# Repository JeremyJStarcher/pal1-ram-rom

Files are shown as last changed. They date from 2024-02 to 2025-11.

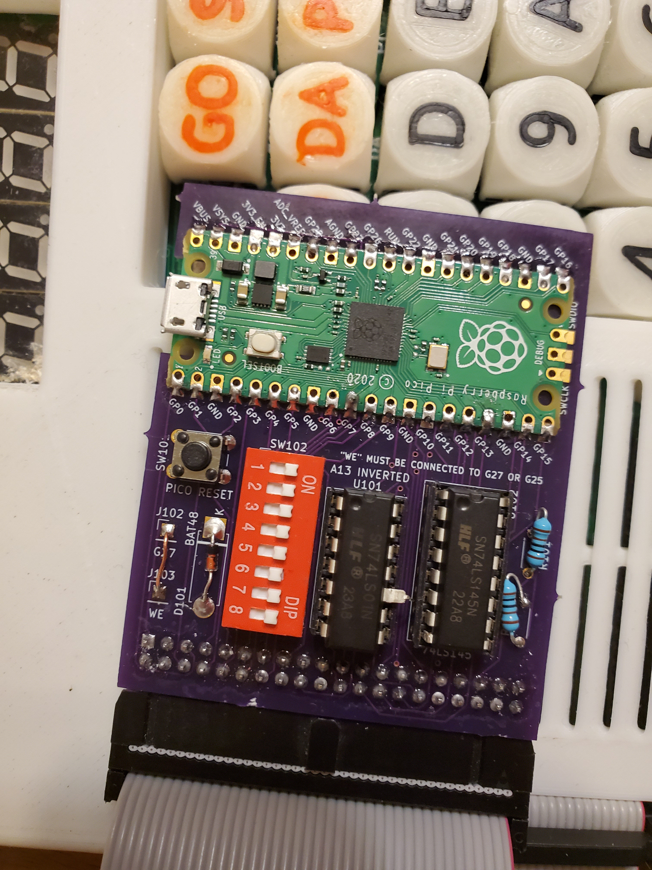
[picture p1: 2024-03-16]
pics/20240308_011445.jpg

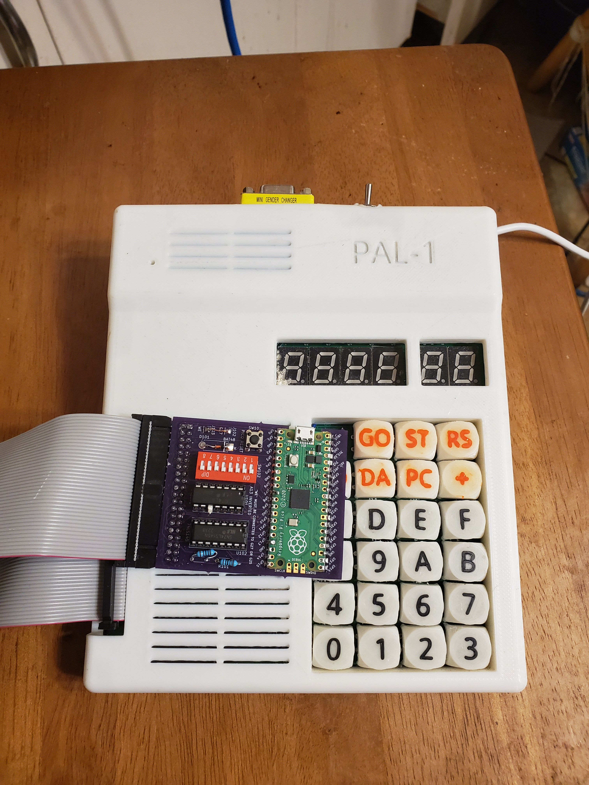
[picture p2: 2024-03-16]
pics/20240308_011429.jpg

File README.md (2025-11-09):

#Breaking change #2

# pal1-ram-rom

Configurable RAM ROM for the PAL-1 (kim-1 clone)

This project is still under development to replace the RAM/ROM and IO expansion board with a Pi Pico.

Current state:  The prototype worked after some manual board rework.

Trying to take over the DEN line via software so all ICs except the Pi Pico can be removed from the board.

## KIM-1 Memory Map

* K0 $0000 - $03FF 1024 bytes of RAM (8*6102)
* K1 $0400 - $07FF free
* K2 $0800 - $0BFF free
* K3 $0C00 - $0FFF free
* K4 $1000 - $13FF free
* K5 $1400 - $16FF free
  * $1700 - $173F I/O, timer of 6530-003
  * $1740 - $177F I/O, timer of 6530-002
  * $1780 - $17BF 64 bytes RAM of 6530-003
  * $17C0 - $17FF 64 bytes RAM of 6530-002
* K6 $1800 - $1BFF 1024 bytes ROM of 6530-003
* K7 $1C00 - $1FFF 1024 bytes ROM of 6530-002

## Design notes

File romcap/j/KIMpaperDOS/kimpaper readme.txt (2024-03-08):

    KIM-1 Mos Technology BIN - papertape format conversion utility

    Hans Otten, June 8 2007, November 2019 March 2020

    Version 1.1 (MOS Technology object format papertape, TASM compatible)

    Applicable license:

    Creative Commons Naamsvermelding-NietCommercieel 2.5 Nederland

    See http://creativecommons.org/licenses/by-nc/2.5/nl/

    Remake of PDP-11 RSX-11M KIM utilities
    Rewrite in Turbo Pascal
    Rewrite in Feepascal compilable on Windows and Linux

    PAPER TAPE FORMAT
    The paper tape is
    a specific format designed to insure error free recovery.  Each byte
    of data to be stored is converted to two half bytes.  The half bytes
    (whose possible values are 0 to F HEX) are translated into their ASCII
    equivalents and written out onto paper tape in this form.

    Each record outputted
    - begins with a ";" character (ASCII 3B) to mark the start of a valid record.
    - The next byte transmitted (max 18 HEX) or (24 10) is the number of data bytes
      contained in the record.
    - The record's starting address High (1 byte, 2 characters),
    - starting address Lo (1 byte, 2 characters),
    - and data (max 24 bytes, 48 characters) follow.

    Each record is terminated by
    - the record's check-sum (2 bytes, 4 characters),
    - a carriage return (ASCII OD),
    - line feed (ASCII 0A),
    - and six "NULL" characters (ASCII 00).

    The last record transmitted has
    - zero data bytes (indicated by 00).
    - The starting address field is replaced by a four digit Hex number
      representing the total number of data records contained in the transmission,
    - followed by the records usual check-sum digits.

    - A "XOFF" character ends the transmission.

    Example

    ;180000FFEEDDCCBBAA0099887766554433221122334455667788990AFC
     --    --  --  --  --  --  --  --  --  --  --  --  --  ----
    ;0000010001
     ----    ----

    See the mpascalint.obj file for a more complicated papertape, created with the assember TASM Commandline
    
    > tasm -65 -g1 mpascalint.asm

    deliverS mpascalint.obj with many different load addresses

    (TASM Assembler Version 3.2 2001 Squak Valley Software)

    In this implementation output of XOFF and NULL characters is suppressed
    Papertape file output is pure ASCII
    While reading a papertapefile all controll chars except LFCR are ignored
    including UTF-8 overhead. UTF-8 is therefore acceptable input.

    Also the last record is ignored after the 00 bytes (for compatibility with TASM320)

    Borland Pascal 7 syntax

    Compiled with Freepascal:
    > fpc -Mtp kimpaper.pas
     
    Long file name support, 32 bit code due to FreePascal! 

E:\BP>kimpaper
KIM-1 Mos Technology BIN - papertape format conversion utiliy, Hans Otten, 2007

Syntax is: KIMPAPER [-[b|p] filename [startaddress]

E:\BP>kimpaper -h
KIM-1 Mos Technology BIN - papertape format conversion utiliy, Hans Otten, 2007
Syntax is: KIMPAPER [-[b|p|h] filename [startaddress]
 first parameter switches
        -h help
        -p convert to papertape
        -b convert to binary

second parameter (first if no parameters, assumed binary to papertape)
               name of file to convert
               .BIN for binary, forces conversion to PAPertape
               .PAP for papertape, forces conversion to BINary

third parameter (assumed 0000 if not present)
    startaddress for BIN to papertape conversion

Files of type .BIN wil force conversion to papertape.PAP
Files of type .PAP wil force conversion to binary .BIN

If the startaddress changes in the record to a different load address nn-contigious witht he previous the current BIN file is closed and a new one,
with a sequence number is created.

For every BIN file the load address is displayed in the screen. 
See the mpascalint.obj and the many BIN files results, each displayed with a corresponding load address.

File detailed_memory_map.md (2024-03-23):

                                                                        
| ADDRESS |      AREA      | LABEL |              FUNCTION               |
|         |                |       |                                     |
|  00EF   |                | PCL   | Program Counter - Low Order Byte    |
|  00F0   |                | PGH   | Program Counter - High Order Byte   |
|  00F1   |     Machine    | P     | Status Register                     |
|  00F2   |     Register   | SF    | Stack Pointer                       |
|         |     Storage    |       |                                     |
|  00F3   |     Buffer     | A     | Accumulator                         |
|  00F4   |                | Y     | Y-Index Register                    |
|  00F5   |                | X     | X-Index Register                    |
|  1700   |                | PAD   | 6530-003 A Data Register            |
|  1701   |   Application  | PADD  | 6530-003 A Data Direction Register  |
|  1702   |        I/O     | PBD   | 6530-003 B Data Register            |
|  1703   |                | PBDD  | 6530-003 B Data Direction Register  |
|  1704   |                |       | 6530-003 Interval Timer             |
|         | Interval Timer |       |   (See Section 1.6 of               |
|         |                |       |    Hardware Manual)                 |
|  170F   |                |       |                                     |
|  17F5   |                | SAL   | Starting Address - Low Order Byte   |
|  17F6   |   Audio Tape   | SAH   | Starting Address - High Order Byte  |
|  17F7   |   Load & Dump  | EAL   | Ending Address - Low Order Byte     |
|  17F8   |                | EAH   | Ending Address - High Order Byte    |
|  17F9   |                | ID    | File Identification Number          |
|  l7FA   |                | NMIL  | NMI Vector - Low Order Byte         |
|  l7FB   |                | NMIH  | NMI Vector - High Order Byte        |
|  l7FC   |   Interrupt    | RSTL  | RST Vector - Low Order Byte         |
|         |    Vectors     |       |                                     |
|  17FD   |                | RSTH  | RST Vector - High Order Byte        |
|  l7FE   |                | IRQL  | IRQ Vector - Low Order Byte         |
|  17FF   |                | IRQH  | IRQ Vector - High Order Byte        |
|  1800   |                | DUMPT | Start Address - Audio Tape Dump     |
|         |  Audio Tape    |       |                                     |
|  1873   |                | LOADT | Start Address - Audio Tape Load     |
|  1C00   | STOP Key + SST |       | Start Address for NMI using KIM     |
|         |                |       | "Save Nachine" Routine (Load in     |
|         |                |       | 17FA & 17FB)                        |
|  17F7   |   Paper Tape   | EAL   | Ending Address - Low Order Byte     |
|  17F8   |    Dump (Q)    | EAH   | Ending Address - High Order Byte    |

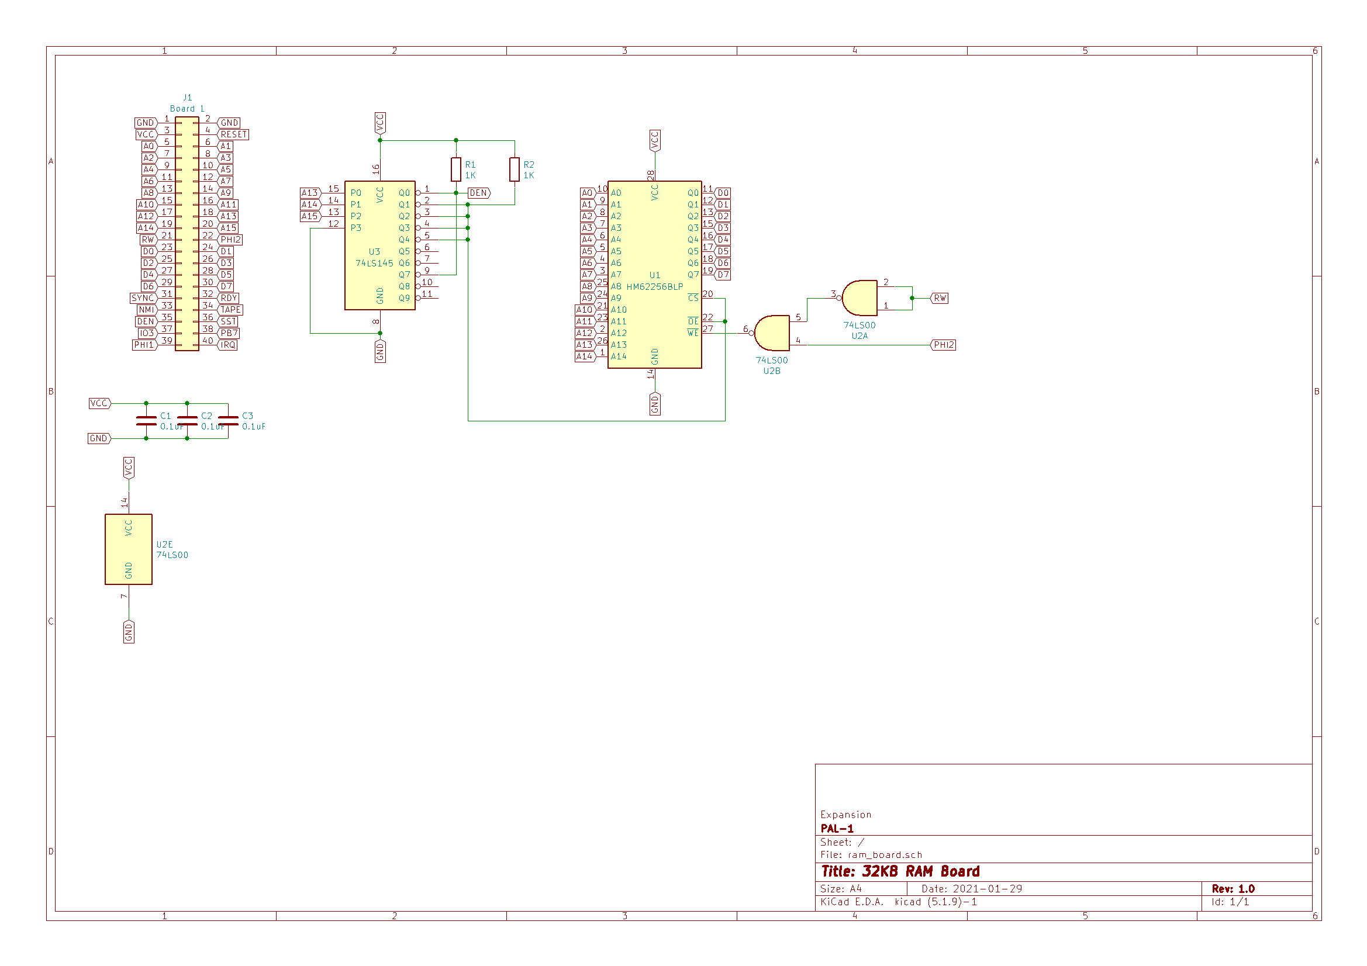
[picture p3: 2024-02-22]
32k_ram_board_schematic.png

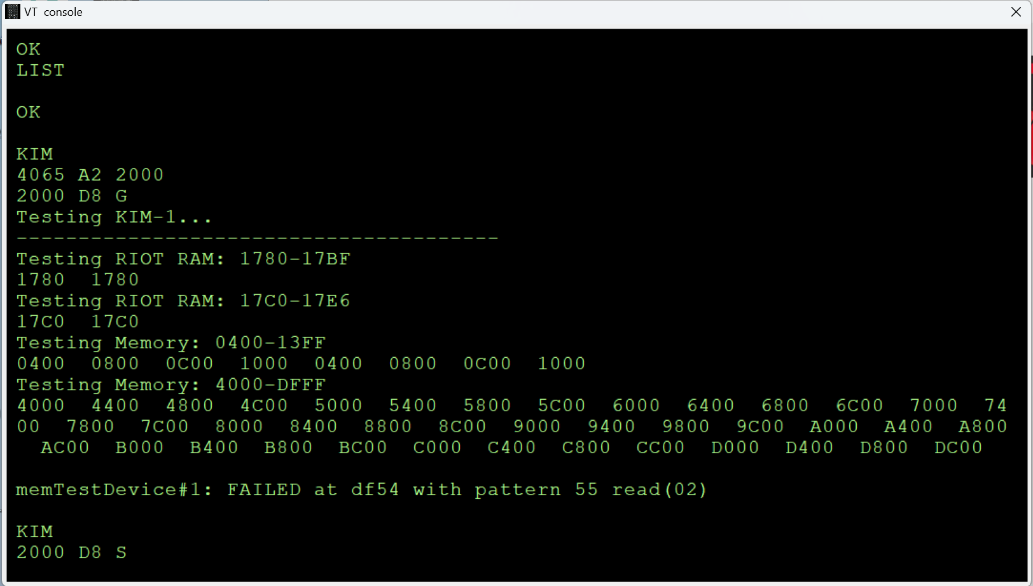
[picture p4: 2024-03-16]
pics/pal1-simulatgor-memtest-error.png

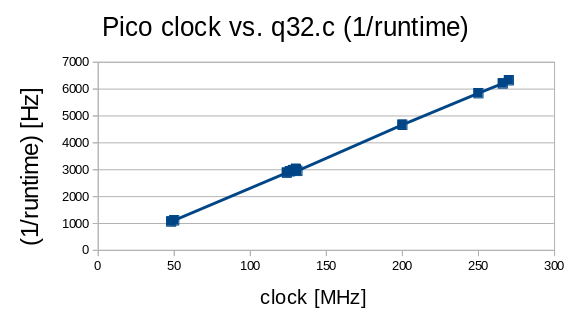
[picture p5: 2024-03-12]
datasheets/overclocking_pico_files/pico_clock_vs_runtime_reciprocal.png

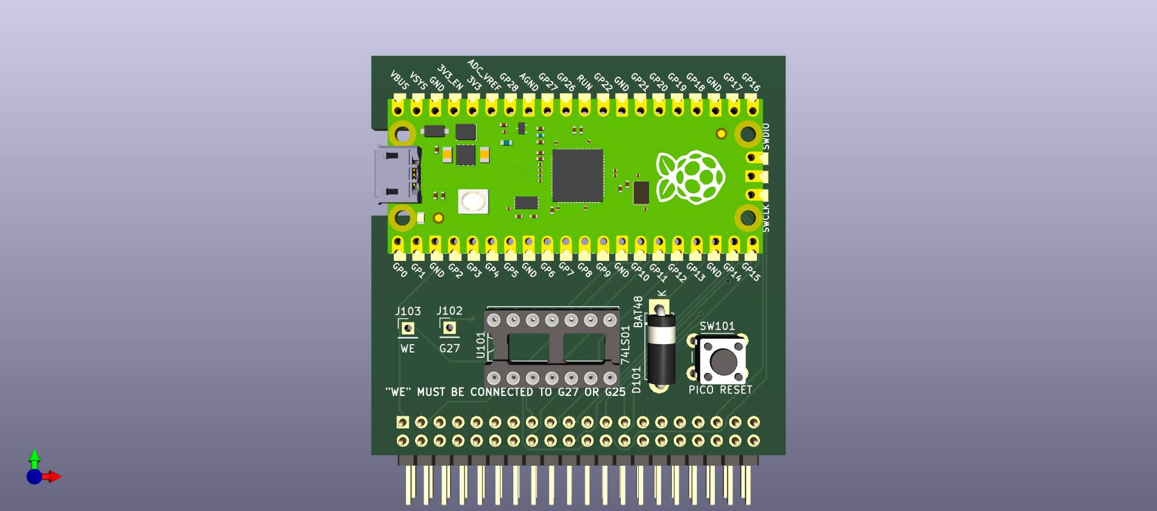
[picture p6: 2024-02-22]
kicad/barebones.png

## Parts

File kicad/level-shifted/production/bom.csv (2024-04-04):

Designator | Footprint | Quantity | Value | LCSC Part #
C101, C102, C103, C104 | C_Disc_D4.7mm_W2.5mm_P5.00mm | 4 | 100nF
D101 | D_A-405_P7.62mm_Horizontal | 1 | 1N4148WS
J101 | PinHeader_2x20_P2.54mm_Vertical | 1 | PAL-1 Expansion Connector
JP101 | PinHeader_1x02_P2.54mm_Vertical | 1 | DECEN ENABLE
R101 | R_Axial_DIN0204_L3.6mm_D1.6mm_P5.08mm_Horizontal | 1 | 1K
SW101 | SW_PUSH_6mm_H4.3mm | 1 | PICO RESET
TP101 | TestPoint_Pad_2.5x2.5mm | 1 | CONNECT TO TP5 ON PICO
U101, U102, U104, U105 | DIP-20_W7.62mm_Socket_LongPads | 4 | 74LVC245
U103 | RPi_Pico_SMD_TH | 1 | Pico

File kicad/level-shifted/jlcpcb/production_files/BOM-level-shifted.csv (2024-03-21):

Comment | Designator | Footprint | LCSC
TXS0108EPW | U101,U102,U103,U105 | TSSOP-20_4.4x6.5mm_P0.65mm | C17206
1K | R101 | R_0603_1608Metric_Pad0.98x0.95mm_HandSolder | C20197
1N4148WS | D102 | D_SOD-323F | C2128
PICO RESET | SW101 | SW_Push_1P1T_XKB_TS-1187A | C2845316
0.1uf | C106 | C_0603_1608Metric_Pad1.08x0.95mm_HandSolder
0.1uf | C101 | C_0603_1608Metric_Pad1.08x0.95mm_HandSolder
Conn_01x09_Socket | J106 | PinHeader_1x09_P1.27mm_Vertical
Conn_01x09_Socket | J107 | PinHeader_1x09_P1.27mm_Vertical
0.1uf | C105 | C_0603_1608Metric_Pad1.08x0.95mm_HandSolder
PAL-1 Expansion Connector | J104 | PinHeader_2x20_P2.54mm_Vertical
0.1uf | C108 | C_0603_1608Metric_Pad1.08x0.95mm_HandSolder
0.1uf | C103 | C_0603_1608Metric_Pad1.08x0.95mm_HandSolder
Conn_01x09_Socket | J105 | PinHeader_1x09_P1.27mm_Vertical
Conn_01x09_Socket | J109 | PinHeader_1x09_P1.27mm_Vertical
0.1uf | C107 | C_0603_1608Metric_Pad1.08x0.95mm_HandSolder
Conn_01x09_Socket | J102 | PinHeader_1x09_P1.27mm_Vertical
Pico | U104 | RPi_Pico_SMD_TH
0.1uf | C102 | C_0603_1608Metric_Pad1.08x0.95mm_HandSolder
0.1uf | C104 | C_0603_1608Metric_Pad1.08x0.95mm_HandSolder
Conn_01x09_Socket | J101 | PinHeader_1x09_P1.27mm_Vertical
Conn_01x09_Socket | J103 | PinHeader_1x09_P1.27mm_Vertical
CONNECT TO TP5 ON PICO | TP101 | TestPoint_Pad_2.5x2.5mm
DECEN ENABLE | JP101 | SolderJumper-2_P1.3mm_Open_RoundedPad1.0x1.5mm
Conn_01x09_Socket | J110 | PinHeader_1x09_P1.27mm_Vertical

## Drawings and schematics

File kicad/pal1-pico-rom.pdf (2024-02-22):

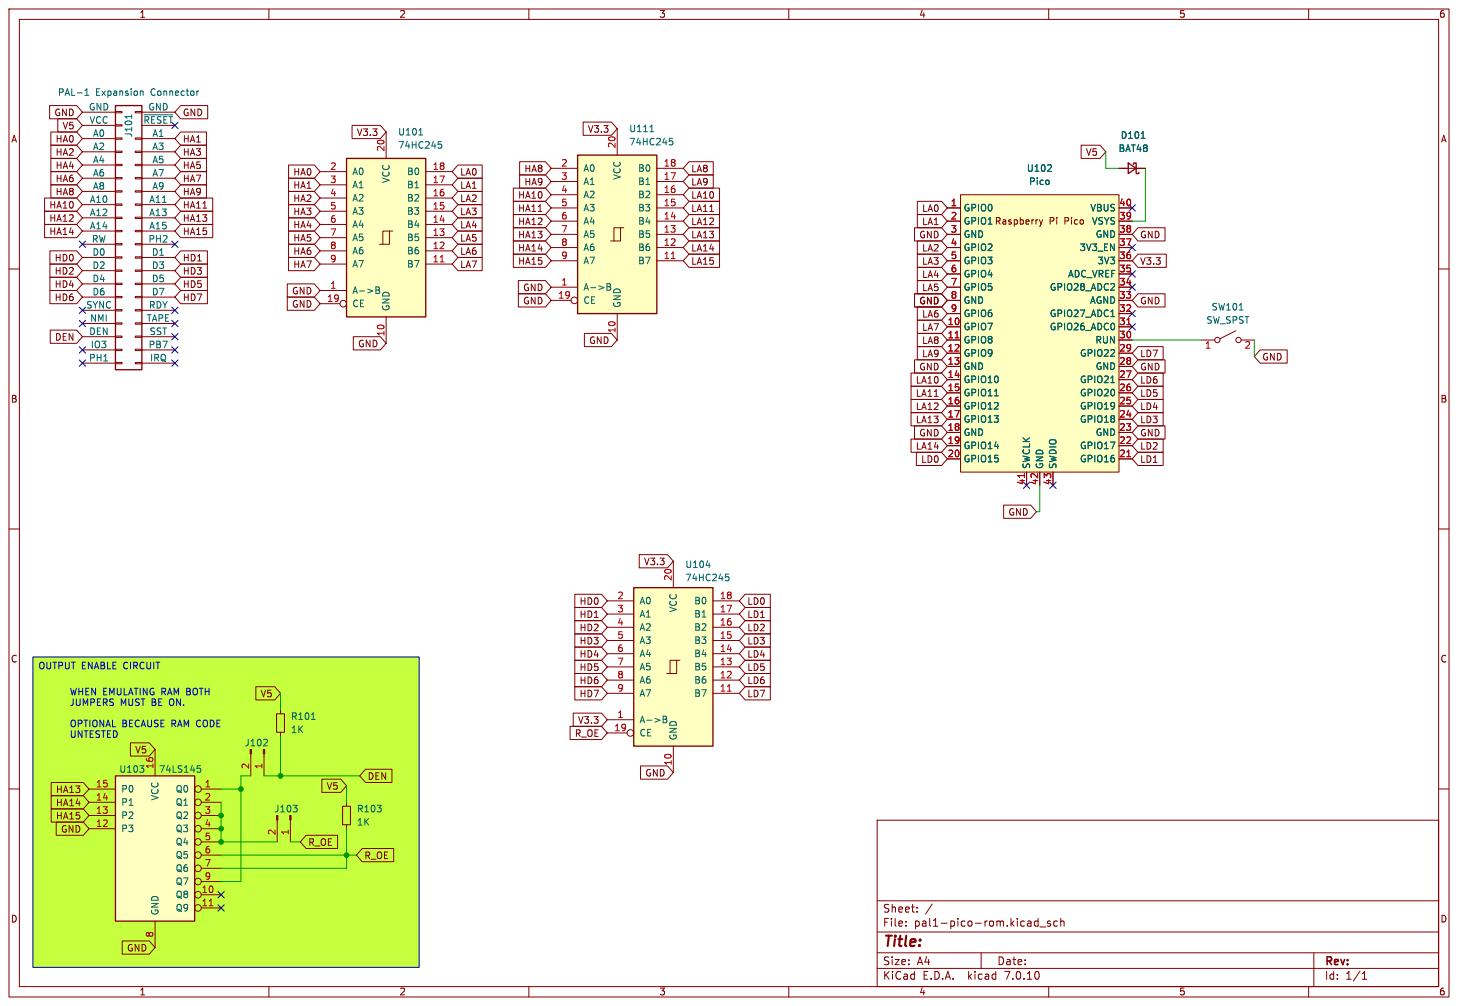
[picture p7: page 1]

LA7 HA1 HA0 WHEN EMULATING RAM BOTH

JUMPERS MUST BE ON. OPTIONAL BECAUSE RAM CODE UNTESTED OUTPUT ENABLE CIRCUIT

Id: 1/1 Title: File: pal1-pico-rom.kicad_sch Sheet: /

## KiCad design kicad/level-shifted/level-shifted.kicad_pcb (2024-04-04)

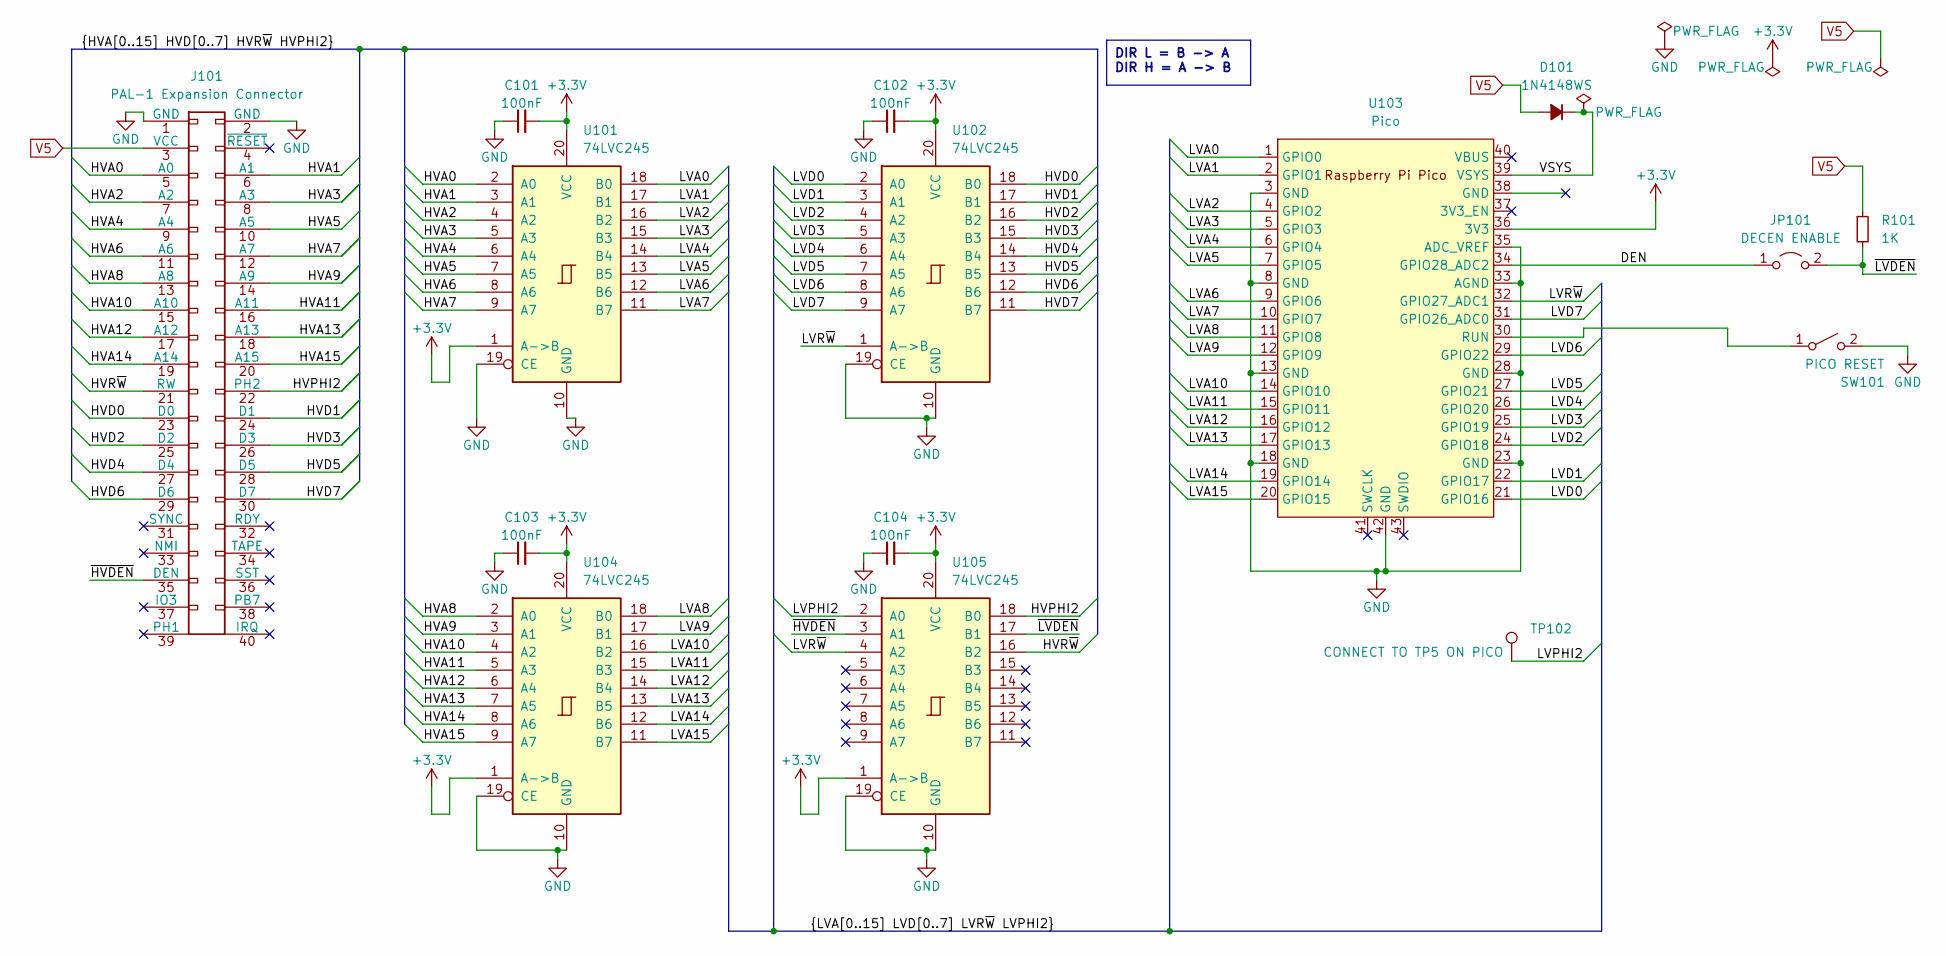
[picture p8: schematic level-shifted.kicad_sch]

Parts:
C101, C102, C103, C104: 100nF; C_Disc_D4.7mm_W2.5mm_P5.00mm
D101: 1N4148WS; D_A-405_P7.62mm_Horizontal; JLCPCB C2128
J101: PAL-1 Expansion Connector; PinHeader_2x20_P2.54mm_Vertical
JP101: DECEN ENABLE; PinHeader_1x02_P2.54mm_Vertical
R101: 1K; R_Axial_DIN0204_L3.6mm_D1.6mm_P5.08mm_Horizontal
SW101: PICO RESET; SW_PUSH_6mm_H4.3mm; MFG# TC-6601-6-260G; JLCPCB C2845316
TP102: CONNECT TO TP5 ON PICO; TestPoint_Pad_2.5x2.5mm
U101, U102, U104, U105: 74LVC245; DIP-20_W7.62mm_Socket_LongPads
U103: Pico; RPi_Pico_SMD_TH

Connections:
+3.3V: C101.2, C102.2, C103.2, C104.2, U101.1 (A->B), U101.20 (VCC), U102.20 (VCC), U103.36 (3V3), U104.1 (A->B), U104.20 (VCC), U105.1 (A->B), U105.20 (VCC)
/DEN: JP101.1 (A), U103.34 (GPIO28_ADC2)
/HVA0: J101.5 (A0), U101.2 (A0)
/HVA1: J101.6 (A1), U101.3 (A1)
/HVA2: J101.7 (A2), U101.4 (A2)
/HVA3: J101.8 (A3), U101.5 (A3)
/HVA4: J101.9 (A4), U101.6 (A4)
/HVA5: J101.10 (A5), U101.7 (A5)
/HVA6: J101.11 (A6), U101.8 (A6)
/HVA7: J101.12 (A7), U101.9 (A7)
/HVA8: J101.13 (A8), U104.2 (A0)
/HVA9: J101.14 (A9), U104.3 (A1)
/HVA10: J101.15 (A10), U104.4 (A2)
/HVA11: J101.16 (A11), U104.5 (A3)
/HVA12: J101.17 (A12), U104.6 (A4)
/HVA13: J101.18 (A13), U104.7 (A5)
/HVA14: J101.19 (A14), U104.8 (A6)
/HVA15: J101.20 (A15), U104.9 (A7)
/HVD0: J101.23 (D0), U102.18 (B0)
/HVD1: J101.24 (D1), U102.17 (B1)
/HVD2: J101.25 (D2), U102.16 (B2)
/HVD3: J101.26 (D3), U102.15 (B3)
/HVD4: J101.27 (D4), U102.14 (B4)
/HVD5: J101.28 (D5), U102.13 (B5)
/HVD6: J101.29 (D6), U102.12 (B6)
/HVD7: J101.30 (D7), U102.11 (B7)
/HVPHI2: J101.22 (PH2), U105.18 (B0)
/HVR~W: J101.21 (RW), U105.16 (B2)
/LVA0: U101.18 (B0), U103.1 (GPIO0)
/LVA1: U101.17 (B1), U103.2 (GPIO1)
/LVA2: U101.16 (B2), U103.4 (GPIO2)
/LVA3: U101.15 (B3), U103.5 (GPIO3)
/LVA4: U101.14 (B4), U103.6 (GPIO4)
/LVA5: U101.13 (B5), U103.7 (GPIO5)
/LVA6: U101.12 (B6), U103.9 (GPIO6)
/LVA7: U101.11 (B7), U103.10 (GPIO7)
/LVA8: U103.11 (GPIO8), U104.18 (B0)
/LVA9: U103.12 (GPIO9), U104.17 (B1)
/LVA10: U103.14 (GPIO10), U104.16 (B2)
/LVA11: U103.15 (GPIO11), U104.15 (B3)
/LVA12: U103.16 (GPIO12), U104.14 (B4)
/LVA13: U103.17 (GPIO13), U104.13 (B5)
/LVA14: U103.19 (GPIO14), U104.12 (B6)
/LVA15: U103.20 (GPIO15), U104.11 (B7)
/LVD0: U102.2 (A0), U103.21 (GPIO16)
/LVD1: U102.3 (A1), U103.22 (GPIO17)
/LVD2: U102.4 (A2), U103.24 (GPIO18)
/LVD3: U102.5 (A3), U103.25 (GPIO19)
/LVD4: U102.6 (A4), U103.26 (GPIO20)
/LVD5: U102.7 (A5), U103.27 (GPIO21)
/LVD6: U102.8 (A6), U103.29 (GPIO22)
/LVD7: U102.9 (A7), U103.31 (GPIO26_ADC0)
/LVR~W: U102.1 (A->B), U103.32 (GPIO27_ADC1), U105.4 (A2)
/VSYS: D101.1 (K), U103.39 (VSYS)
/~HVDEN: J101.35 (DEN), U105.3 (A1)
/~LVDEN: JP101.2 (B), R101.2, U105.17 (B1)
GND: C101.1, C102.1, C103.1, C104.1, J101.1 (GND), J101.2 (GND), SW101.2 (B), U101.10 (GND), U101.19 (CE), U102.10 (GND), U102.19 (CE), U103.3 (GND), U103.8 (GND), U103.13 (GND), U103.18 (GND), U103.23 (GND), U103.28 (GND), U103.33 (AGND), U103.35 (ADC_VREF), U103.42 (GND), U104.10 (GND), U104.19 (CE), U105.10 (GND), U105.19 (CE)
LVPHI2: TP102.1, U105.2 (A0); also elsewhere on the board
unnamed: SW101.1 (A), U103.30 (RUN)
V5: D101.2 (A), J101.3 (VCC), R101.1

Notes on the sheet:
DIR L = B -> A DIR H = A -> B

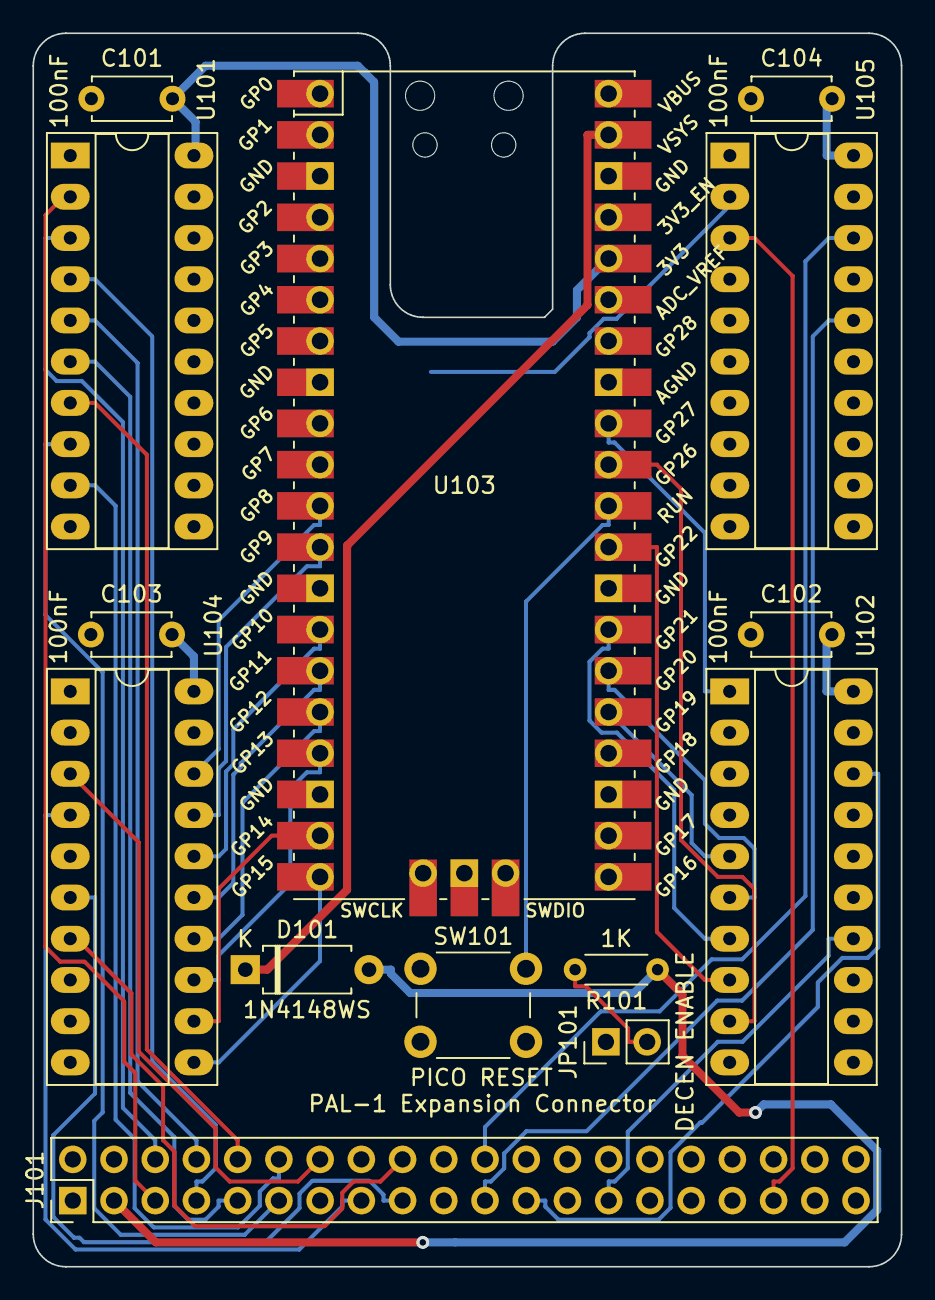
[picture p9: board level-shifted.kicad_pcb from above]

Board: 4 copper layers, 53.5 x 76.0 mm, 15 parts (1 on the bottom side), 60 nets.

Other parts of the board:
TP101: CONNECT TO TP5 ON PICO; TestPoint_Pad_2.5x2.5mm

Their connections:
LVPHI2: TP101.1; also elsewhere on the board

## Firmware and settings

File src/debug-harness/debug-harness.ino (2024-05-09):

String a;

#define ARRAY_SIZE(arr) (sizeof(arr) / sizeof((arr)[0]))

const int ADDR_LOW = 0x2000;
const int ADDR_HIGH = 0xFFF0;

#define TEST_LSB
#define TEST_MSB
#define TEST_WRITE

const int AA0 = 52;
const int AA1 = 53;

const int AA2 = 50;
const int AA3 = 51;

const int AA4 = 48;
const int AA5 = 49;

const int AA6 = 46;
const int AA7 = 47;

const int AA8 = 44;
const int AA9 = 45;

const int AA10 = 42;
const int AA11 = 43;

const int AA12 = 40;
const int AA13 = 41;

const int AA14 = 38;
const int AA15 = 39;

// R/W which the CPU sets high to read and low to write.
const int RW = 36;
const int PHI2 = 37;

const int DATA0 = 34;
const int DATA2 = 32;
const int DATA4 = A8;
const int DATA6 = 28;

const int DATA1 = 35;
const int DATA3 = 33;
const int DATA5 = 31;
const int DATA7 = 29;

const int RESET = A0;
const int PHI1 = A1;
const int IO3 = A2;
const int DEN = A3;
const int NMI = A4;
const int SYNC = A5;

const int IRQ = 7;
const int ZPB7 = 6;
const int SST = 5;
const int TAPE = 4;
const int RDY = 3;

const int address_lines[] = { AA0, AA1, AA2, AA3, AA4, AA5, AA6, AA7, AA8, AA9, AA10, AA11, AA12, AA13, AA14, AA15 };
const int data_lines[] = { DATA0, DATA1, DATA2, DATA3, DATA4, DATA5, DATA6, DATA7 };

void readString() {
  while (!Serial.available()) {
  }
  while (Serial.available()) {
    a = Serial.readString();  // read the incoming data as string
    //Serial.println(a);
  }
}

uint8_t slowRead(int pin) {
  uint8_t v;
  //delay(100);
  v = digitalRead(pin);
  //delay(100);
  return v;
}

uint8_t readDataPins() {
  uint8_t value = 0;
  uint8_t v;
  for (int i = 0; i < ARRAY_SIZE(data_lines); i++) {
    int pin = data_lines[i];
    pinMode(pin, INPUT);
    v = slowRead(pin);
    value |= v << i;
  }
  return value;
}


uint16_t readAddressPins() {
  set_data_lines_direction(INPUT);

  uint16_t value = 0;
  for (int i = 0; i < ARRAY_SIZE(address_lines); i++) {
    value |= (digitalRead(address_lines[i]) << i);
  }
  return value;
}

void writeDataToPins(uint8_t value) {
  for (int i = 0; i < ARRAY_SIZE(data_lines); i++) {
    int pin = data_lines[i];
    pinMode(pin, OUTPUT);
    digitalWrite(pin, value & (1 << i) ? HIGH : LOW);
    //delay(1 * 1000);
  }
}

void writeAddressToPins(uint16_t value) {
  for (int i = 0; i < ARRAY_SIZE(address_lines); i++) {
    digitalWrite(address_lines[i], value & (1 << i) ? HIGH : LOW);
  }
}

void set_address_lines_direction(int mode) {
  for (size_t i = 0; i < ARRAY_SIZE(address_lines); i++) {
    pinMode(address_lines[i], mode);
  }
}

void set_data_lines_direction(int mode) {
  for (size_t i = 0; i < ARRAY_SIZE(data_lines); i++) {
    int pin = data_lines[i];
    pinMode(pin, mode);
  }
}

void dump_addr_data(int addr, int data) {
  Serial.print("ADDR = ");
  Serial.print(addr, HEX);
  Serial.print(" Data = ");
  Serial.print(data, HEX);
  Serial.print(" ");
  Serial.print(data, BIN);

  Serial.print(" MATCH? ");
  Serial.print(addr & 0x00FF, HEX);

  Serial.println();
}

void reset_pins() {
  set_address_lines_direction(OUTPUT);
  set_data_lines_direction(INPUT);

  pinMode(DEN, INPUT);
  pinMode(RW, OUTPUT);
  pinMode(PHI2, OUTPUT);
  digitalWrite(RW, HIGH);
}

uint8_t read_data(uint16_t addr) {
  digitalWrite(PHI2, LOW);
  writeAddressToPins(addr);
  digitalWrite(PHI2, HIGH);
  uint8_t data = readDataPins();
  return data;
}

void setup() {
  uint8_t data;
  uint8_t is_match;

  //Initialize serial and wait for port to open:
  Serial.begin(9600);
  while (!Serial) {
    ;  // wait for serial port to connect. Needed for native USB port only
  }

  delay(1 * 1000);

  Serial.println();
  Serial.println("====RESET===");
  reset_pins();

#ifdef TEST_LSB
  reset_pins();
  Serial.println("LOAD LSB INTO RAM AND PRESS ENTER");
  readString();
  Serial.println("RUNNING LSB TEST");
  for (int addr = ADDR_LOW; addr < ADDR_HIGH; addr += 1) {
    data = read_data(addr);
    is_match = (addr & 0x00FF) == data;
    if (!is_match) {
      Serial.print("LSB ");
      dump_addr_data(addr, data);
    }
  }
#endif


#ifdef TEST_MSB
  reset_pins();
  Serial.println("LOAD MSB INTO RAM AND PRESS ENTER");
  readString();
  Serial.println("RUNNING MSB TEST");
  for (int addr = ADDR_LOW; addr < ADDR_HIGH; addr += 1) {
    data = read_data(addr);
    is_match = (addr & 0xFF00) == data << 8;
    if (!is_match) {
      Serial.print("MSB ");
      dump_addr_data(addr, data);
    }
  }
#endif

#ifdef TEST_WRITE
  reset_pins();
  Serial.println("RUNNING WRITE TEST");
  for (int addr = ADDR_LOW; addr < ADDR_HIGH; addr += 1) {
    int flipped = ~(addr)&0x00FF;
    digitalWrite(PHI2, LOW);
    digitalWrite(RW, LOW);
    writeAddressToPins(addr);
    writeDataToPins(flipped);

    digitalWrite(PHI2, HIGH);
    digitalWrite(RW, HIGH);

    data = readDataPins();

    if (data != flipped) {
      Serial.print("FLIP TEST ");
      dump_addr_data(addr, data);
    }
  }
#endif

  Serial.println("<-- DONE -->");
}


void loop() {
}

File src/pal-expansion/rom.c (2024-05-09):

/*
 * KIM-1 ROM/RAM
 * Based off the PICORom project by Nick Bild (nick.bild@gmail.com)
 *
 * Heavily modified for RAM/ROM and sideloading data.
 *
 * March 2024
 */

#define EMULATE_RIOT

#include <malloc.h>
#include <stdio.h>
#include <stdlib.h>

// #include "6532_timer.h"
#include "6532_timer.c"
#include "clockspeed.h"
#include "commands.h"
#include "hardware/clocks.h"
#include "hardware/vreg.h"
#include "pico/multicore.h"
#include "pico/stdlib.h"
#include "pin_definitions.h"
#include "rambuf.h"
#include "tusb.h"

#define FLASH_SIZE (2 * 1024 * 1024)
#define NELEMS(x) (sizeof(x) / sizeof((x)[0]))
#define LED_PIN 25

int ledValue = 0;

uint32_t addr_mask = 0;
uint32_t data_mask = 0;

uint32_t addr_pins[] = {A0, A1, A2,  A3,  A4,  A5,  A6,  A7,
                        A8, A9, A10, A11, A12, A13, A14, A15};
uint32_t data_pins[] = {D0, D1, D2, D3, D4, D5, D6, D7};
uint32_t ctrl_pins[] = {WE, PHI2};

uint32_t getTotalHeap(void);
uint32_t getFreeHeap(void);

void setup_gpio(void);
void main_memory_loop(void);

uint16_t ADDR_BOTTOM = (uint16_t)0x2000;
uint16_t ADDR_TOP = ((uint16_t)0xFFFF);

#define HI_UINT16(a) (((a) >> 8) & 0xFF)
#define LO_UINT16(a) ((a)&0xFF)

// this address should always never change value
// to stop things that probe RAM
#define IO_ADDRESS 0xFFF7

extern char __flash_binary_end;

void init_ux() {
  // wait for USB serial
  while (!tud_cdc_connected()) {
    sleep_ms(100);
  }

  printf("\n\n\n");

  printf("addr_mask          : 0x%08x\n", addr_mask);
  printf("addr_mask          : ");
  print_binary(addr_mask, 32);
  printf("\n");

  printf("data_mask          : 0x%08x\n", data_mask);
  printf("data_mask          : ");
  print_binary(data_mask, 32);
  printf("\n");

  printf("Free heap size     : %ld\n", getFreeHeap());

  uintptr_t end = (uintptr_t)&__flash_binary_end;
  printf("Binary ends at     : %08x\n", end);

  uintptr_t flashleft = (XIP_BASE + FLASH_SIZE) - end;

  printf("Bottom of flash    : 0x%08x\n", XIP_BASE);
  printf("Top of flash       : 0x%08x\n", XIP_BASE + FLASH_SIZE);
  printf("Flash Left         : 0x%08x\n", flashleft);
  printf("Flash Left         : %11db %.2fk %.2fm\n", flashleft,
         flashleft / 1024.0, flashleft / 1024.0 / 1024.0);
  printf("clk_sys            : %ukHz %.2fmHz\n",
         frequency_count_khz(CLOCKS_FC0_SRC_VALUE_CLK_SYS),
         frequency_count_khz(CLOCKS_FC0_SRC_VALUE_CLK_SYS) / 1000.0);

  printf("Size of sys_state   : %u\n", sizeof sys_state);
  printf("                    : %u\n", sizeof sys_state / 1024);
  printf(" (Flash pages)      : %u R %u\n", sizeof sys_state / (4 * 1024),
         sizeof sys_state % (4 * 1024));

  command_loop(XIP_BASE, FLASH_SIZE);
}

int main() {
  // Set system clock speed.
  // 400 MHz
  //  vreg_set_voltage(VREG_VOLTAGE_1_30);
  //  set_sys_clock_pll(1600000000, 4, 1);

  set_sys_clock_khz(CLOCK_SPEED_HIGH, false);
  vreg_set_voltage(VREG_VOLTAGE_1_30);

  stdio_init_all();

  // Specify contents of emulated ROM.
  setup_memory_contents();

  // GPIO setup.
  setup_gpio();
  gpio_put(DEN, 0);

  multicore_launch_core1(main_memory_loop);

  init_ux();
}

void __time_critical_func(main_memory_loop)() {
  uint_fast16_t addr;
  uint_fast16_t data;
  uint32_t all;
  uint32_t we_n;
  uint32_t cs;
  uint32_t phi2;

#ifdef EMULATE_RIOT
  uint_fast8_t riot_phi2_state = false;
  uint_fast8_t riot_range;
  uint_fast8_t riot_underflow;
#endif

  while (true) {
    all = gpio_get_all();

    addr = all & (uint32_t)0xFFFF;
    phi2 = (all & (uint32_t)(1 << PHI2));
    we_n = (all & (uint32_t)(1 << WE));

    //   printf("WE %d -- PHI2 %d SS- %d \r\n", !!we_n, !!phi2,
    //   riot_phi2_state);

#ifdef EMULATE_RIOT
    if (phi2 && !riot_phi2_state) {
      // Rising edge
      riot_phi2_state = true;

#if 0
      uint8_t data2 = peekram(addr);

      printf("ADDR = %04x ", addr);
      print_binary(addr, 16);
      printf("WE %d -- PHI2 %d DATA = %02X ", !!we_n,  !!phi2,
             data2);
      print_binary(data2, 8);
      printf("\r\n");
#endif
    }

    if (!phi2 && riot_phi2_state) {
      // Falling edge

      riot_counter--;
      riot_phi2_state = false;
      // Do this calculation when we are not as busy
      riot_underflow = riot_counter & (1 << 18);
    }

#endif

#ifdef EMULATE_RIOT
    riot_range = addr >= 0x1700 && addr <= 0x170F;
    if (riot_range) {
      if (phi2) {
        if (we_n == 0) {
          data = (uint32_t)((all & data_mask) >> D0);
          // inline 16_to_8
          data |= ((data >> (D7 - D0)) & 1) << 7;

          // Inline this looking for speed
          // Comes close but is still a bit slow
          addr = addr & 0x000F;
          period_type = periodtypemap[addr];
          riot_counter = data << shiftmap[addr];
        } else {
          // data = riot_read_timer(addr);

          if (riot_underflow) {
            // Let the casting get rid of the rest
            data = riot_counter;
          } else {
            data = riot_counter >> shiftmap2[period_type];
          }

          // inline 8 to 16
          data |= ((data & (1 << 7)) ? 1 : 0) << D7 - D0;
          gpio_put(DEN, 0);
          gpio_set_dir_masked(data_mask, data_mask);
          gpio_put_masked(data_mask, data << D0);
          continue;
        }
      } else {
        gpio_set_dir_masked(data_mask, 0);
        continue;
      }
    }
#endif

    //    pokeram(addr, 1 << 7 | 1 << 6 | 1 << 5 | 1 << 4 | 1 << 3  | 1 << 2 | 1
    //    << 1);

    data = sys_state.memory[addr];
    int decen = (data & 1 << IN_USE_BIT) ? 1 : 0;

    gpio_put(DEN, decen);

    if (decen && phi2) {
      if (we_n == 0 && (data & (1 << RO_MEMORY_BIT)) == 0) {
        data = (uint32_t)((all & data_mask) >> D0);

#if 0
      printf("WDATA = %02X ", data);
      print_binary(data, 8);
      printf("\r\n");
#endif

        sys_state.memory[addr] = data | (1 << IN_USE_BIT);
      } else {
        gpio_set_dir_masked(data_mask, data_mask);
        gpio_put_masked(data_mask, data << D0);
      }
    } else {
      gpio_set_dir_masked(data_mask, 0);
    }
  }
}

void setup_gpio() {
  size_t i;
  int gpio;
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

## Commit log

2024-03-08 Updated code so that CS works correctly, started next PCB version
    [barebones.kicad_pcb, barebones.kicad_sch, freerouting.dsn]
2024-03-09 RAM working and updating. PHI2 respected.
    [barebones.kicad_pcb, barebones.kicad_sch]
2024-03-10 Bit of PCB cleanup for removed features.
    [barebones.kicad_pcb, barebones.kicad_sch]
2024-03-10 Cleaned up commands to upper case, added address decoding test support
2024-03-11 New PCB that is 100% software defined
    [barebones.kicad_pcb, barebones.kicad_sch]
2024-03-12 Reworked build process to be simplier
    [rom.c]
2024-03-12 Swapped cores so that CORE1 can shut down during flashing
    The flashing requires interrupts and the easiest (only?) way to
    shut down interrupts on CORE1 is to reset it back to the default
    state of not running anything.
    [rom.c]
2024-03-15 RAM card input translated to upper case.
2024-03-16 Fixed up PCB design due to flat in last PCB
    [barebones.kicad_pcb]
2024-03-16 Resolved issue of RAM getting corrupted and unsable
    [rom.c]
2024-03-17 Timer/IO regions excluded from being shadowed. All RAM now shadowed.
2024-03-17 Removed old version of PCB
    [pal1-pico-rom.kicad_pcb, pal1-pico-rom.kicad_sch]
2024-03-17 Added a level shifted version
    [level-shifted.kicad_pcb, level-shifted.kicad_sch]
2024-03-20 New board prepared with the level shifters in place
    [BOM-level-shifted.csv, freerouting.dsn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]
2024-03-21 Updated the PCB to use the old (normal) pin numberings and ordered the board
    [BOM-level-shifted.csv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]
2024-03-23 Added basic RIOT timer test baseline
2024-03-24 Added basic RIOT timer support but it is too slow to be reliable.
    [rom.c]
2024-03-24 Bunch of changes to try to get the timer to quit locking up -- none worked.
2024-03-25 Re-enabled 400Mhz - inlined riot timer write
2024-03-25 Isolated the RIOT timer code and workedon a lower clock speed
2024-04-04 Added a board with multiplexed bus lines to experiment
    [mplex.kicad_pcb, mplex.kicad_sch]
2024-04-04 PCB for the level shifted version
    [bom.csv, designators.csv, freerouting.dsn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]
2024-04-06 Brought back old copy of the RIOT timer / baked test into the pico code
2024-04-06 Got the RIOT timer working well.
2024-04-07 New GETCH function that converts to upper case
2024-04-08 GETCH intercepted to force things to upper case
